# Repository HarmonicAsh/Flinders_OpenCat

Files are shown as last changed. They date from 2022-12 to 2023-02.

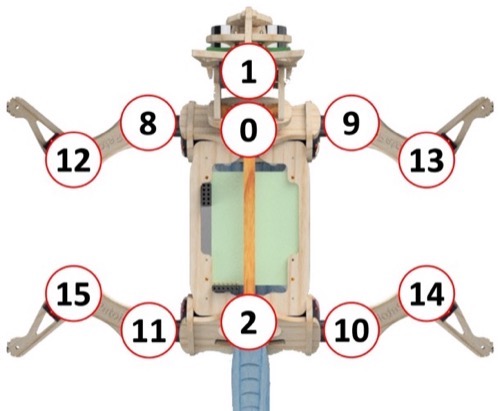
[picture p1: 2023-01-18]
OpenCat1801/pyUI/resources/Nybble.jpeg

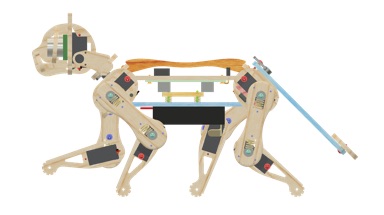
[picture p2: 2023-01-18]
OpenCat1801/pyUI/resources/NybbleWalk.jpeg

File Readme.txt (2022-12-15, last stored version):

**Welcome to the Flinders University OpenCat Project repository!**

Simplfied step by step assembly guide for Nybble:
1. Upload firmwire to the Nyboard using the Petoi Desktop app. Be sure to zero the IMU (gyro sensor) on a flat benchtop or Nybble will not balance well.
https://docs.petoi.com/desktop-app/firmware-uploader

2. To control Nybble with a Rasberry Pi, a pre 4 model must be used due to compatability issues. Follow the Petoi guide to set up the serial port of the Rasberry Pi to interface with the Nybble.
https://docs.petoi.com/api/raspberry-pi-serial-port-as-an-interface

3. Download the OpenCat repository to the Rasberry Pi. With a Github account, the repository can be set up on your Pi using the Pi terminal:
$ sudo apt-get update
$ sudo apt-get install git
$ git config --global user.email "Your@email.com"
$ git config -- global user.name "Your GITHUB username"

To clone the repository to your device, then use:
$ git clone https://github.com/PetoiCamp/OpenCat.git

ALternatively, using the same link, download and install manually.

4. ArdSerial is used to issue serial commands from the Rasberry Pi to the Nyboard. 

https://www.putty.org/
disable ghetty

ardSerial
calibrate
Open cat web interface
ifconfig : find IP address for SSH and VNC to remote control via Wifi

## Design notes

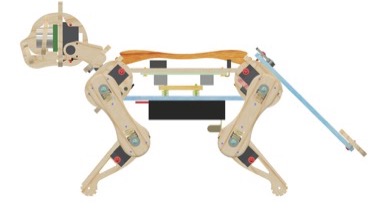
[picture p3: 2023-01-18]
OpenCat1801/pyUI/resources/NybbleStand.jpeg

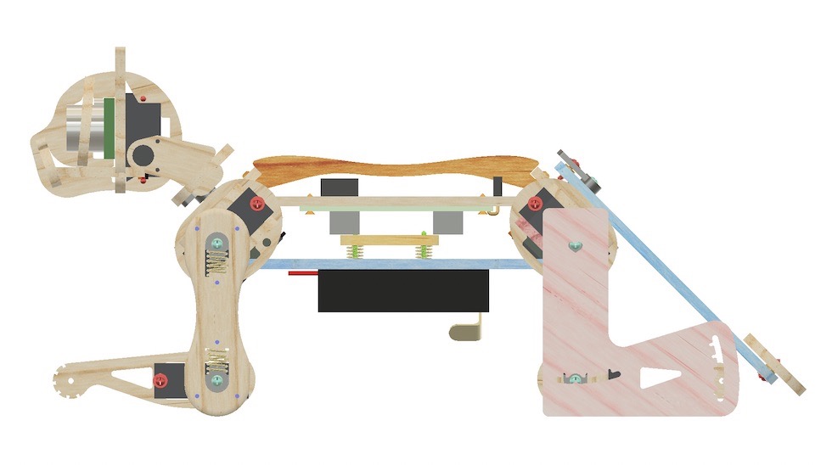
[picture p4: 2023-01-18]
OpenCat1801/pyUI/resources/NybbleRuler.jpeg

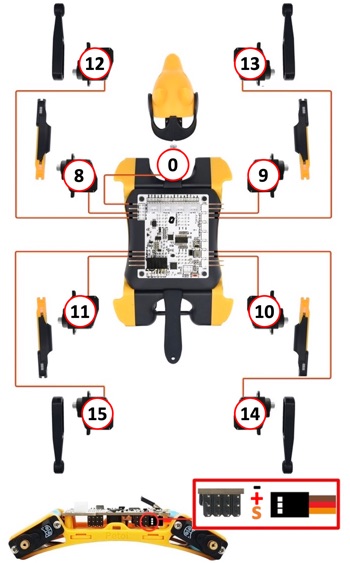
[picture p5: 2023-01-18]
OpenCat1801/pyUI/resources/BittleWire.jpeg

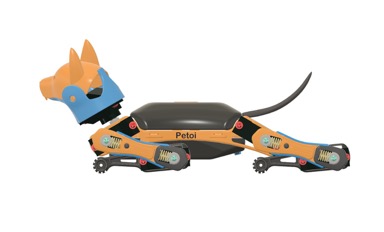
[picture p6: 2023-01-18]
OpenCat1801/pyUI/resources/BittleRest.jpeg

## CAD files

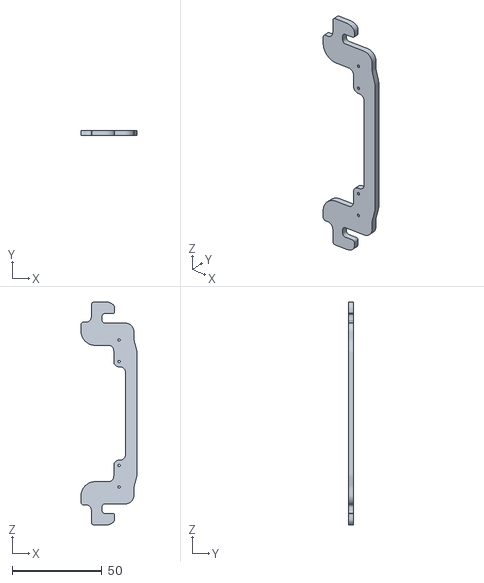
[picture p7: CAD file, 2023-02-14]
CAD components/Nybble_y1.stl
31.3 x 3.00 x 124.4

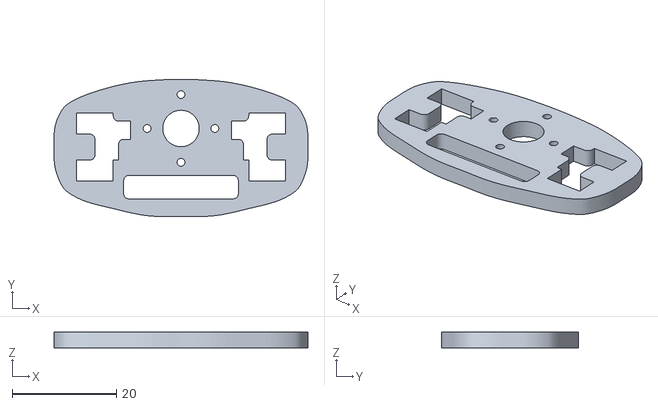
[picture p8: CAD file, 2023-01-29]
CAD components/NybbleDIY/Neck_Base_Plate_MG90S.stl
48.7 x 26.3 x 3.00

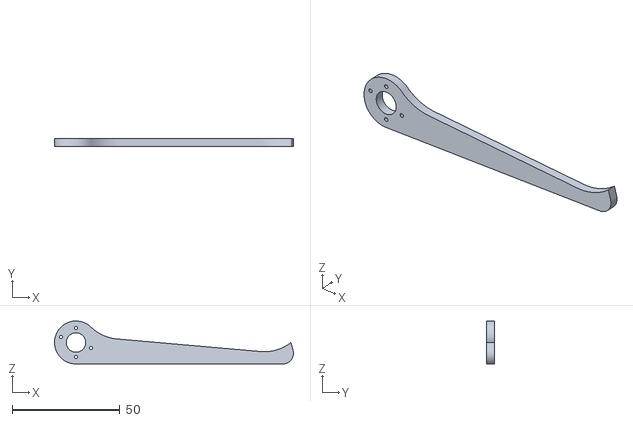
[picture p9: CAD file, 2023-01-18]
OpenCat1801/ModuleTests/testServo/servoTorqueArm.stl
111.2 x 3.50 x 20.0

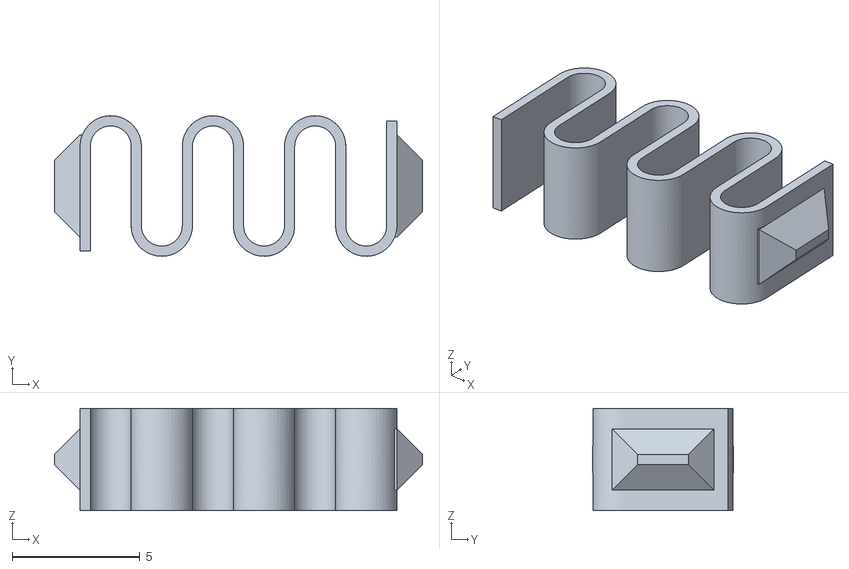
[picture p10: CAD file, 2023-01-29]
CAD components/NybbleDIY/Spring_4.0_.4.stl
14.4 x 5.50 x 4.00

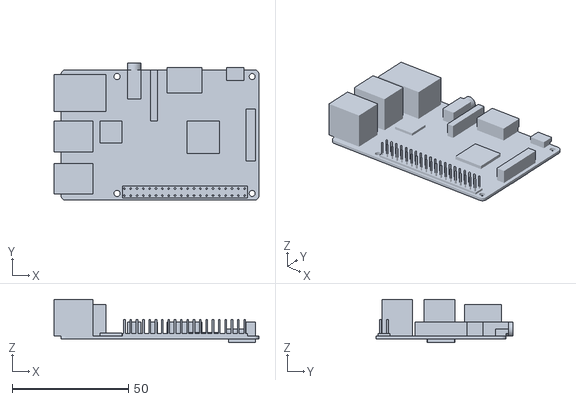
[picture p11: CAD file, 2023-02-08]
CAD components/pi_v6.stl
88.0 x 59.0 x 18.6

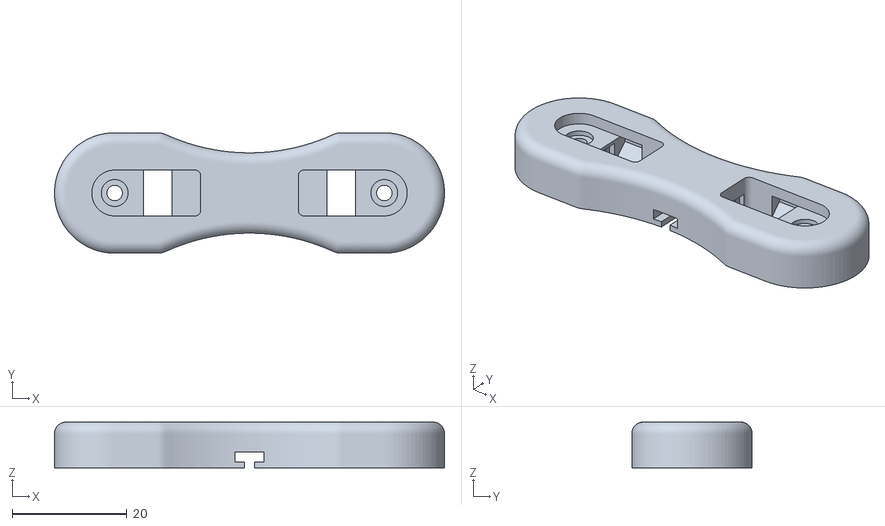
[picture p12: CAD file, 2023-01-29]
CAD components/NybbleDIY/Thigh.stl
68.0 x 21.0 x 8.00

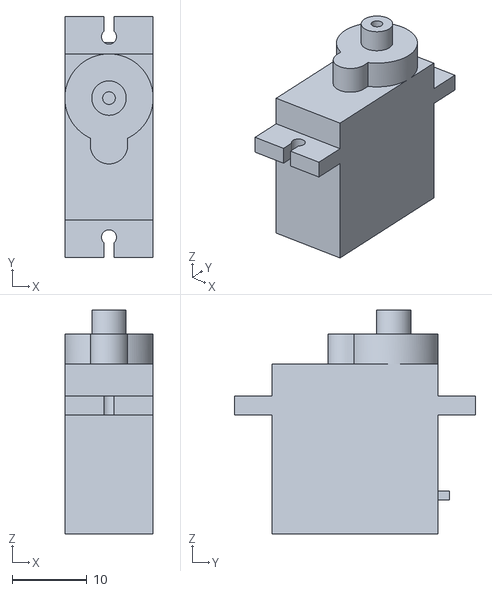
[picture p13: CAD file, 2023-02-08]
CAD components/SG90_v7.stl
11.8 x 32.2 x 29.9

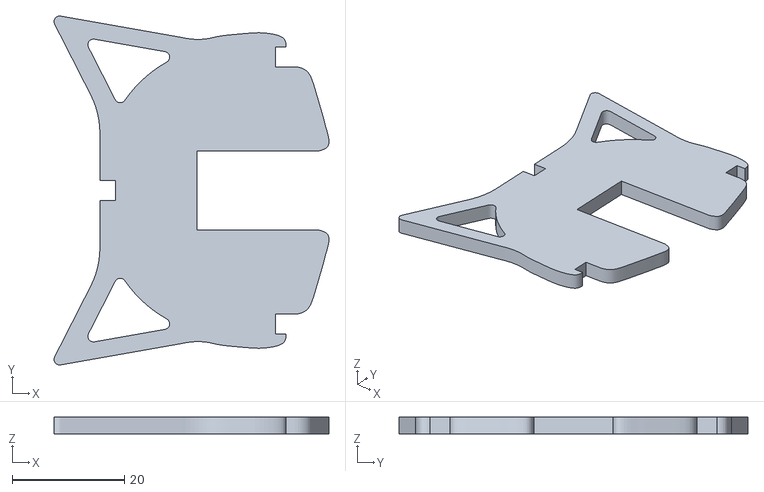
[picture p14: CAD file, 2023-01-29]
CAD components/NybbleDIY/Ears_MG90S.stl
48.9 x 62.1 x 3.00

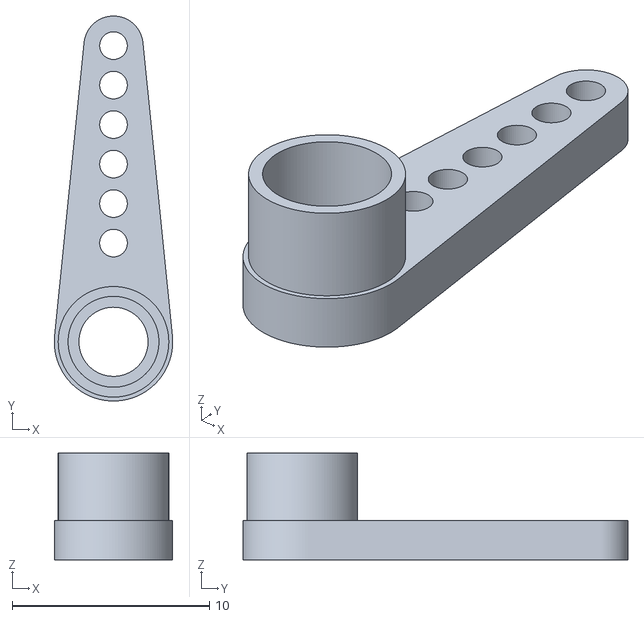
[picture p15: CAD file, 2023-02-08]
CAD components/SG90_arm_v2.stl
6.00 x 19.5 x 5.40

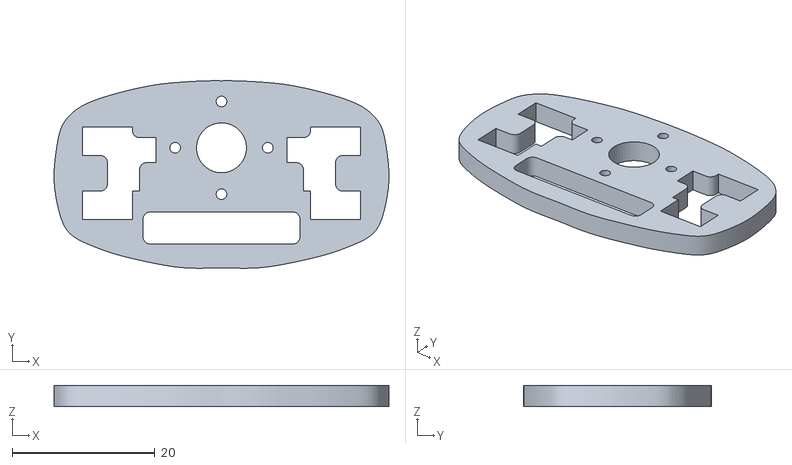
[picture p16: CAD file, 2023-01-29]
CAD components/NybbleDIY/Neck_Base_Plate.stl
47.0 x 26.3 x 3.00

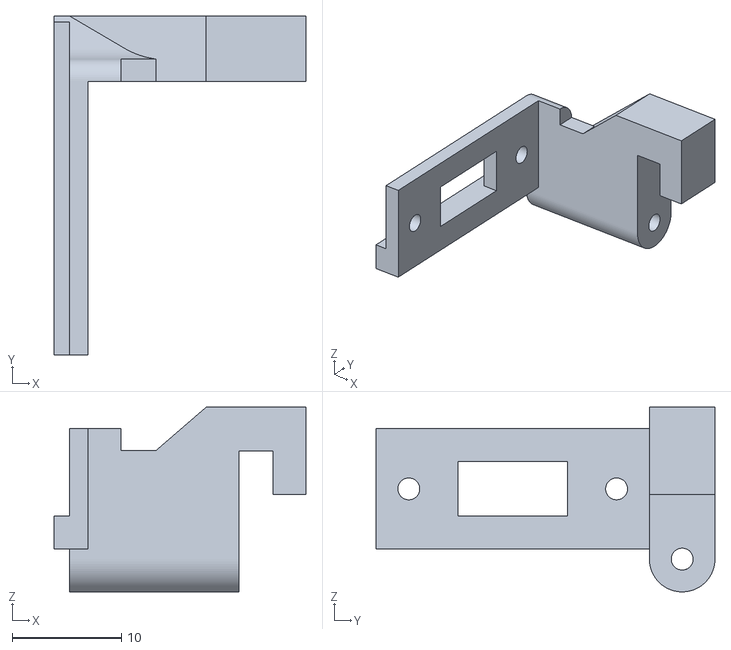
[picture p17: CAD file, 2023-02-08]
CAD components/Pi3B_spacer_R_switch2.stl
23.0 x 31.0 x 16.9

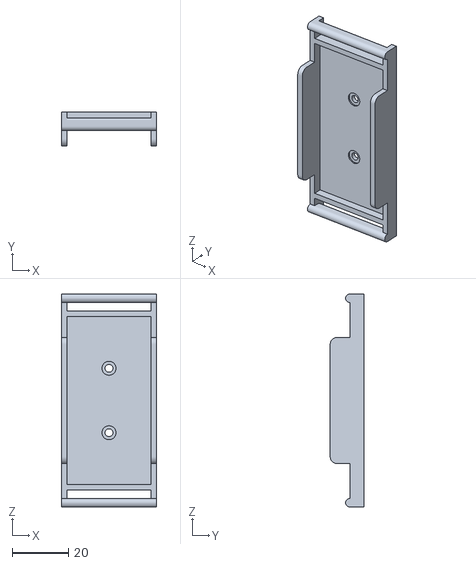
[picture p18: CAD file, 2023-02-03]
CAD components/Battery_holder_2.stl
34.0 x 12.0 x 76.0

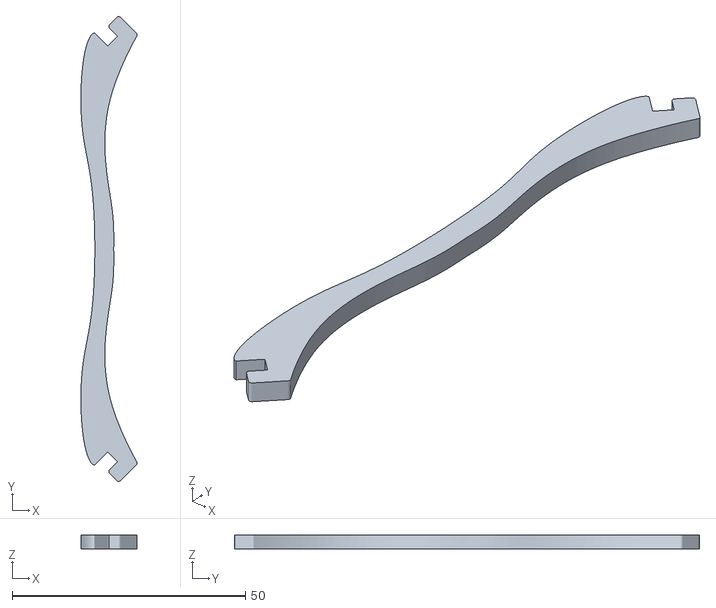
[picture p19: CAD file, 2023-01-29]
CAD components/NybbleDIY/Spine.stl
12.1 x 99.7 x 3.00

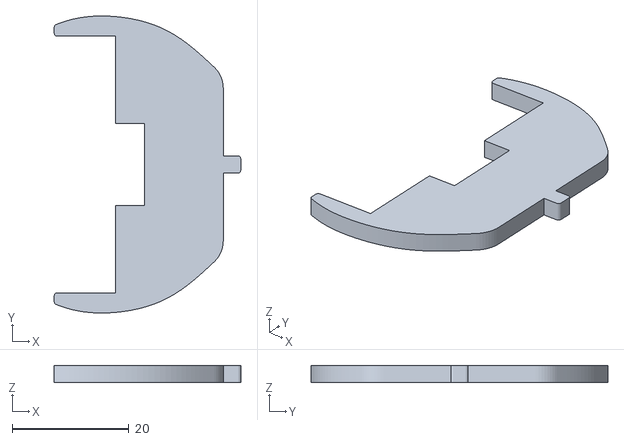
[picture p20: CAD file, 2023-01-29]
CAD components/NybbleDIY/Chin_MG90S.stl
32.0 x 50.9 x 3.00

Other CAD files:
CAD components/Pi3B_spacer_R_switch.stl
CAD components/battery mount rear.stl
CAD components/NybbleDIY/Controller_Mount.stl
CAD components/Battery mount front.stl
CAD components/815 Servo Driver 16 Channel.ipt
CAD components/Base_modded.ipt
CAD components/Base_modded.stl
CAD components/Battery mount front.ipt
CAD components/Battery_holder.iam
CAD components/Battery_holder.ipt
CAD components/Battery_holder_2.ipt
CAD components/Battery_holder_upper.stl
CAD components/Battery_holer_lower.stl
CAD components/Battery_short_holder.ipt
CAD components/Battery_temp.ipt
CAD components/Battery_template.ipt
CAD components/BellyPlate.ipt
CAD components/Braces.ipt
CAD components/Braces.stl
CAD components/Cat_head.iam
CAD components/Chest_Hips.ipt
CAD components/Dowel.ipt
CAD components/Imported Components/Battery_holer_lower/Battery_holer_lower.ipt
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

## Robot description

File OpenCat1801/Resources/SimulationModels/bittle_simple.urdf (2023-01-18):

<?xml version="0.0" ?>
<robot name="bittle_simple">
	<link name="torso">
		<inertial>
			<origin rpy="0.00000 -0.00000 0.00000" xyz="0.00000 0.00000 0.00000"/>
			<mass value="20.00000"/>
			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
		</inertial>
		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
	</link>
	<link name="link1_2">
		<inertial>
			<origin rpy="0.00000 -0.00000 0.00000" xyz="0.00000 0.00000 0.00000"/>
			<mass value="0.00000"/>
			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
		</inertial>
	</link>
	<link name="lfs">
		<inertial>
			<origin rpy="0.00000 -0.00000 0.00000" xyz="0.00000 0.00000 0.00000"/>
			<mass value="0.60000"/>
			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
		</inertial>
		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
	</link>
	<link name="link1_4">
		<inertial>
			<origin rpy="0.00000 -0.00000 0.00000" xyz="0.00000 0.00000 0.00000"/>
			<mass value="0.00000"/>
			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
		</inertial>
	</link>
	<link name="lfk">
		<inertial>
			<origin rpy="0.00000 -0.00000 0.00000" xyz="0.00000 0.00000 0.00000"/>
			<mass value="1.70000"/>
			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
		</inertial>
		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
	</link>
	<link name="link1_6">
		<inertial>
			<origin rpy="0.00000 -0.00000 0.00000" xyz="0.00000 0.00000 0.00000"/>
			<mass value="0.00000"/>
			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
		</inertial>
	</link>
	<link name="rfs">
		<inertial>
			<origin rpy="0.00000 -0.00000 0.00000" xyz="0.00000 0.00000 0.00000"/>
			<mass value="0.60000"/>
			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
		</inertial>
		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
	</link>
	<link name="link1_8">
		<inertial>
			<origin rpy="0.00000 -0.00000 0.00000" xyz="0.00000 0.00000 0.00000"/>
			<mass value="0.00000"/>
			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
		</inertial>
	</link>
	<link name="rfk">
		<inertial>
			<origin rpy="0.00000 -0.00000 0.00000" xyz="0.00000 0.00000 0.00000"/>
			<mass value="1.70000"/>
			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
		</inertial>
		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
	</link>
	<link name="link1_10">
		<inertial>
			<origin rpy="0.00000 -0.00000 0.00000" xyz="0.00000 0.00000 0.00000"/>
			<mass value="0.00000"/>
			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
		</inertial>
	</link>
	<link name="lbs">
		<inertial>
			<origin rpy="0.00000 -0.00000 0.00000" xyz="0.00000 0.00000 0.00000"/>
			<mass value="0.60000"/>
			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
		</inertial>
		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
	</link>
	<link name="link1_12">
		<inertial>
			<origin rpy="0.00000 -0.00000 0.00000" xyz="0.00000 0.00000 0.00000"/>
			<mass value="0.00000"/>
			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
		</inertial>
	</link>
	<link name="lbk">
		<inertial>
			<origin rpy="0.00000 -0.00000 0.00000" xyz="0.00000 0.00000 0.00000"/>
			<mass value="1.70000"/>
			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
		</inertial>
		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
	</link>
	<link name="link1_14">
		<inertial>
			<origin rpy="0.00000 -0.00000 0.00000" xyz="0.00000 0.00000 0.00000"/>
			<mass value="0.00000"/>
			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
		</inertial>
	</link>
	<link name="rbs">
		<inertial>
			<origin rpy="0.00000 -0.00000 0.00000" xyz="0.00000 0.00000 0.00000"/>
			<mass value="0.60000"/>
			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
		</inertial>
		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
	</link>
	<link name="link1_16">
		<inertial>
			<origin rpy="0.00000 -0.00000 0.00000" xyz="0.00000 0.00000 0.00000"/>
			<mass value="0.00000"/>
			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
		</inertial>
	</link>
	<link name="rbk">
		<inertial>
			<origin rpy="0.00000 -0.00000 0.00000" xyz="0.00000 0.00000 0.00000"/>
			<mass value="1.70000"/>
			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
		</inertial>
		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
	</link>
	<joint name="lfsj" type="continuous">
		<parent link="torso"/>
		<child link="link1_2"/>
		<dynamics damping="1.0" friction="0.0001"/>
		<origin rpy="0.00000 -0.00000 0.00000" xyz="-0.04850 0.05050 0.00000"/>
		<axis xyz="1.00000 0.00000 0.00000"/>
	</joint>
	<joint name="jointfix_1_2" type="fixed">
		<parent link="link1_2"/>
		<child link="lfs"/>
		<dynamics damping="1.0" friction="0.0001"/>
		<origin rpy="0.00000 -0.00000 0.00000" xyz="0.00000 0.02300 0.00000"/>
		<axis xyz="0.00000 0.00000 0.00000"/>
	</joint>
	<joint name="lfkj" type="continuous">
		<parent link="lfs"/>
		<child link="link1_4"/>
		<dynamics damping="1.0" friction="0.0001"/>
		<origin rpy="0.00000 -0.00000 0.00000" xyz="0.00750 0.02300 0.00000"/>
		<axis xyz="1.00000 0.00000 0.00000"/>
	</joint>
	<joint name="jointfix_0_4" type="fixed">
		<parent link="link1_4"/>
		<child link="lfk"/>
		<dynamics damping="1.0" friction="0.0001"/>
		<origin rpy="0.00000 -0.00000 0.00000" xyz="0.00000 0.02425 0.00000"/>
		<axis xyz="0.00000 0.00000 0.00000"/>
	</joint>
	<joint name="rfsj" type="continuous">
		<parent link="torso"/>
		<child link="link1_6"/>
		<dynamics damping="1.0" friction="0.0001"/>
		<origin rpy="0.00000 -0.00000 0.00000" xyz="0.04850 0.05050 0.00000"/>
		<axis xyz="1.00000 0.00000 0.00000"/>
	</joint>
	<joint name="jointfix_3_6" type="fixed">
		<parent link="link1_6"/>
		<child link="rfs"/>
		<dynamics damping="1.0" friction="0.0001"/>
		<origin rpy="0.00000 -0.00000 0.00000" xyz="0.00000 0.02300 0.00000"/>
		<axis xyz="0.00000 0.00000 0.00000"/>
	</joint>
	<joint name="rfkj" type="continuous">
		<parent link="rfs"/>
		<child link="link1_8"/>
		<dynamics damping="1.0" friction="0.0001"/>
		<origin rpy="0.00000 -0.00000 0.00000" xyz="-0.00750 0.02300 0.00000"/>
		<axis xyz="1.00000 0.00000 0.00000"/>
	</joint>
	<joint name="jointfix_2_8" type="fixed">
		<parent link="link1_8"/>
		<child link="rfk"/>
		<dynamics damping="1.0" friction="0.0001"/>
		<origin rpy="0.00000 -0.00000 0.00000" xyz="0.00000 0.02425 0.00000"/>
		<axis xyz="0.00000 0.00000 0.00000"/>
	</joint>
	<joint name="lbsj" type="continuous">
		<parent link="torso"/>
		<child link="link1_10"/>
		<dynamics damping="1.0" friction="0.0001"/>
		<origin rpy="0.00000 -0.00000 0.00000" xyz="-0.04850 -0.05050 0.00000"/>
		<axis xyz="1.00000 0.00000 0.00000"/>
	</joint>
	<joint name="jointfix_5_10" type="fixed">
		<parent link="link1_10"/>
		<child link="lbs"/>
		<dynamics damping="1.0" friction="0.0001"/>
		<origin rpy="0.00000 -0.00000 0.00000" xyz="0.00000 -0.02300 0.00000"/>
		<axis xyz="0.00000 0.00000 0.00000"/>
	</joint>
	<joint name="lbkj" type="continuous">
		<parent link="lbs"/>
		<child link="link1_12"/>
		<dynamics damping="1.0" friction="0.0001"/>
		<origin rpy="0.00000 -0.00000 0.00000" xyz="0.00750 -0.02300 0.00000"/>
		<axis xyz="1.00000 0.00000 0.00000"/>
	</joint>
	<joint name="jointfix_4_12" type="fixed">
		<parent link="link1_12"/>
		<child link="lbk"/>
		<dynamics damping="1.0" friction="0.0001"/>
		<origin rpy="0.00000 -0.00000 0.00000" xyz="0.00000 -0.02425 0.00000"/>
		<axis xyz="0.00000 0.00000 0.00000"/>
	</joint>
	<joint name="rbsj" type="continuous">
		<parent link="torso"/>
		<child link="link1_14"/>
		<dynamics damping="1.0" friction="0.0001"/>
		<origin rpy="0.00000 -0.00000 0.00000" xyz="0.04850 -0.05050 0.00000"/>
		<axis xyz="1.00000 0.00000 0.00000"/>
	</joint>
	<joint name="jointfix_7_14" type="fixed">
		<parent link="link1_14"/>
		<child link="rbs"/>
		<dynamics damping="1.0" friction="0.0001"/>
		<origin rpy="0.00000 -0.00000 0.00000" xyz="0.00000 -0.02300 0.00000"/>
		<axis xyz="0.00000 0.00000 0.00000"/>
	</joint>
	<joint name="rbkj" type="continuous">
		<parent link="rbs"/>
		<child link="link1_16"/>
		<dynamics damping="1.0" friction="0.0001"/>
		<origin rpy="0.00000 -0.00000 0.00000" xyz="-0.00750 -0.02300 0.00000"/>
		<axis xyz="1.00000 0.00000 0.00000"/>
	</joint>
	<joint name="jointfix_6_16" type="fixed">
		<parent link="link1_16"/>
		<child link="rbk"/>
		<dynamics damping="1.0" friction="0.0001"/>
		<origin rpy="0.00000 -0.00000 0.00000" xyz="0.00000 -0.02425 0.00000"/>
		<axis xyz="0.00000 0.00000 0.00000"/>
	</joint>
</robot>

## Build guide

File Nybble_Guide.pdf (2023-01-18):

## Nybble: Basic Assembly and Serial Connections

S.Thiele, Flinders University
08/01/2023, revision 1
- A simplified instruction set, developed directly from Petoi instructions, designed to be a simple step-by-step set of instructions to build your own Nybble cat! This guide is aimed at those who find that they struggle with direction in establishing the fundamentals of playing with Nybble. All Nybble related information in this guide is available in more detail from Petoi. I also highly recommend the Petoi Forum (https://www.petoi.camp/) for ideas, inspiration and additional assistance. It is full of great content and a good way to learn how to make your Nybble stand out from the crowd!

## 1 Assembly and Setting up the Raspberry Pi Interface

1. Upload firmwire to the Nyboard using the Petoi Desktop app. Be sure to zero the IMU (gyro sensor) on a flat bench-top or Nybble will not balance well. See Petoi firmware uploader (https://docs.petoi.com/desktop-app/firmware-uploader) for additional information.
2. Carry out the assembly process, following the process outlined by Petoi: Petoi Nybble Instructions. (https://nybble.petoi.com/chapter1) Joint calibration can be carried out via USB as per the instructions guide or with the serial input after step 6.
3. To use a Raspberry Pi for controlling Nybble, download the OpenCat repository to the Raspberry Pi. With a Github account, the repository can be set up on your Pi using the Pi terminal:
sudo apt-get update
sudo apt-get install git
Optionally, to link your own GitHub account:
git config –global user.email ”Your@email.com”
git config – global user.name ”Your GITHUB username”
4. To clone the OpenCat repository to your device, then use:
git clone https://github.com/PetoiCamp/OpenCat.git

Alternatively, using the same link, download and install manually. All Git repositories can be downloaded by simply replacing the URL with the URL of the desired repository.
5. Follow the Petoi guide (https://docs.petoi.com/api/raspberry-pi-serial-port-as-an-interface) to set up the serial port of the Raspberry Pi to interface with the Nybble.
6. ArdSerial.py is used to issue serial commands from the Raspberry Pi to the Nyboard. Serial commands can be found here: Petoi Serial Protocol. (https://docs.petoi.com/serial-protocol#arduino-ide-as-an-interface)

## 2 Issuing commands to the Raspberry Pi via Wi-Fi and a remote terminal

1. Connect the Raspberry Pi to the same WiFi network as the control device.
2. Using ifconfig in the Raspberry Pi terminal, find IP address of the Raspberry Pi.
ifconfig
3. Download the latest PuTTY client (https://www.putty.org/) to the control device. A remote connection to the Raspberry Pi can be established by following simple guide. (https://raspberrypi4dummies.wordpress.com/2013/03/17/connect-to-the-raspberry-pi-via-ssh-putty/)

4. After establishing the connection, use the PuTTY terminal as per steps 1.5 and 1.6 to issue commands to Nybble!

## 3 Using the OpenCatWeb Interface

1. Download or clone the OpenCatWeb repository (https://github.com/leukipp/OpenCatWeb.git) to your device
2. Follow the setup instructions in the read-me either from the cloned repository or here. (https://github.com/leukipp/OpenCatWeb) Stop when you reach the section called ”First Start”, changes must be made to enable the connection to be made.
3. Enable SSH in the Raspberry Pi terminal and configuration settings and acquire the IP address of the Raspberry Pi on the network using ifconfig.
sudo raspi-config

ifconfig

4. html.escape supersedes cgi.escape from Python 3.2 onwards (issues arise in OpenCatWeb scripts as a result of this) and additional compatability issues may occur. A workaround is to install Python 2.7 and alter app.py to run on the older version. Begin by installing Python 2.7, using the Raspberry Py terminal.
sudo apt-get update

sudo apt-get install python2.7

reboot

5. Open app.py from the OpenCatWeb directy with a text or Python editor. Alterations are made to use the known IP address and to reconfigure the script to use Python 2.7. Observe the following sections of code:
!/usr/bin/python | at line 1
HOST = ’0.0.0.0’ | at line 8
The first line must be altered to run Python 2.7, and new lines added directly beneath to reconfigure the default location of packages, as these will not be installed in the standard Python 2.7 location. Replace line 1 with the following 3 lines:
!/usr/bin/python2.7
import sys
sys.path.append(‘/usr/lib/python3/dist-packages‘)
Now simply input the IP address of your Raspberry Pi into the HOST line and save the code. For example: HOST = ’192.168.0.32’
6. Next, bus.py must be altered to suit the correct serial configuration. Code lines 9 to 18 are responsible for setting up the serial connection. Note in particular, the following 2 lines:
port = ’/dev/ttyAMA0’,
baudrate = 57600,
To allow OpenCatWeb to function, these must be re-defined to suit the ttyS0 serial port. Changing the lines as follows:
port = ’/dev/ttyS0’,
baudrate = 115200,

7. Ensure that Flask and serial are installed: pip install Flask
pip install serial
8. You should now be able to resume following the read-me (https://github.com/leukipp/OpenCatWeb) for OpenCatWeb from the ”First Start” section.

## 4 Arduino Serial Output

1. The Arduino serial monitor can be used with both Bluetooth or a USB cable as an interface. Connect the desired adaptor to the Nyboard and either connect the USB cable to your control device or confirm that Nyble is visible over Bluetooth.
2. Open the Arduino IDE, choose an Arduino UNO as the board and choose the correct COM port. If using a USB cable, you should be able to view which COM port is connected to Nybble, and alternatively determine the COM port of your Bluetooth connection. Open the serial monitor and ensure that the settings of the serial monitor is set to ”No line ending” and ”115200 baud”.
3. If a succesful connection is made, Nybble will begin by relaying some data back to the serial monitor. If you can clearly see information from the Nybble, you are ready to go! Issue commands to Nybble observed in the Serial Protocol (https://docs.petoi.com/serial-protocol) documentation to control her!

## 5 Raspberry Pi with Ubuntu Via PuTTY

1. Install Ubuntu via the Raspberry Pi imager. (https://www.raspberrypi.com/software/) The server version can be used for simplicity, performs much better on older Raspberry Pi hardware. It is necessary to open the advanced options section on the main page, and enable SSH and enter desired log-in details of the Raspberry Pi, to allow access over a network connection. For additional information, follow the Ubuntu Installation Guide. (https://ubuntu.com/tutorials/how-to-install-ubuntu-on-your-raspberry-pi#1-overview)
2. Download the latest PuTTY client (https://www.putty.org/) to the control device. A remote connection to the Raspberry Pi can be established by following simple guide.You (https://raspberrypi4dummies.wordpress.com/2013/03/17/connect-to-the-raspberry-pi-via-ssh-putty/) can use the host name given during the installation setup to connect to the Raspberry Pi, or the IP address.
3. Ubuntu lacks some essential Python packages required to use ardSerial.py. It is useful to install the Python pip package as well as tkinster.
sudo apt-get update
sudo apt install python3-pip
sudo apt install python3.8-tk
sudo dmesg | grep tty [check that ttyS0 is enabled or see what it is about⁉]
Can install a desktop UI if needed: sudo apt install xubuntu-desktop sudo apt install lubuntu-desktop

## 6 Kinematic Model- Skill Creation

Kinematic Model (https://github.com/ger01d/kinematic-model-opencat) pip3 install –upgrade numpy sudo apt-get install libatlas-base-dev

## 7 Flinders University Customisations

This section introduces adaptations made during the assembly and testing of the Nybble project.

1. Customised Battery Holder:
A replacement battery holder was developed to suit a 7.4 850mAh LiPo battery (https://www.auselectronicsdirect.com.au/7.4v-850mah-lipo-2s-battery-pack-with-jst-connecto) featuring a JST connector, using an inline switch. (https://www.jaycar.com.au/inline-jst-switch-kit/p/SS0826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) The mounting was designed to retain Nybble’s sliding battery mechanism, to allow for adjustments to her centre of gravity. The current itteration of the design is entirely 3D printed, and is ready to use after installation to the lower frame of Nybble. Due to tolerancing from the print, drilling of the base may be required to fit the original locating collars, however heating the collars with a soldering iron is also effective.
2. Petoi/Raspberry Pi Camera Holder:
As Nybble does not have the facilities to equip a camera, as Bittle would, a clip on camera mount was designed. It sits over the head of Nybble, and clips around the ultrasonic sensor. The camera design has 2 versions, one to suit the Petoi camera (https://www.petoi.com/products/intelligent-camera-module) and one to suit a Raspberry Pi camera, (https://www.raspberrypi.com/products/camera-module-v2/) to better facilitate projects requiring additional functionality. Details about setting up the camera can be found here. (https://docs.petoi.com/extensible-modules/mu-camera)
3. Raspberry Pi 3B spaced mounts:
As Nybble was designed around a Raspberry Pi 3A, with a smaller footprint than later models, the design of the body inhibits the use of full scale Pi models, with issues accessing most of the USB ports. Spacers have been designed, that use the Nyboard mounting screws to secure them to the body, and allows self-tapping screws to be fitted to support the Raspberry Pi. Additional requirements are a 2x5 pin spacer and some self-tapping screws.

## 8 Acknowledgments

Here will be acknowledgements to the Cat man himself, leukipp and other sources

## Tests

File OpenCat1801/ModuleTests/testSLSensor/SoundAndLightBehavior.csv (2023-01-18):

LIGHT | READING | THRESHOLD
brighter | lower
darker | higher | 850
LIGHT |  | SOUND
_LEVEL | _CHANGE | _LEVEL | _BEHAVIOR
dark |  | low | rest
 |  | high | sit
high |  | low | sit
 |  | high | stand
 | fast light
 | fast dim
bright |  |  | proportional

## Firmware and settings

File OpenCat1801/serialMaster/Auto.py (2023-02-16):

#!/usr/bin/python3
# -*- coding: UTF-8 -*-

#Req pyserial and pip3
#sudo apt-get install python3-tk
#Use to install Pip3 as req: sudo apt-get -y install python3-pip
#https://wavlist.com/animals-cats-20-wavs/ cat sounds found here <-


import random
import sys
import time
import math
from pygame import mixer
sys.path.append("..")
from ardSerial import *
from SR04 import *
        
         
def load_sound():
        mixer.init()  #Initialise pigame mixer for audio
        print("Loading sounds...")
        global cat1
        global cat2
        global cat3
        global cat4
        global cat5
        cat1 = mixer.Sound("cat1.wav")   #load wav files
        cat2 = mixer.Sound("cat2.wav")   #load wav files
        cat3 = mixer.Sound("cat3.wav")   #load wav files
        cat4 = mixer.Sound("cat4.wav")   #load wav files
        cat5 = mixer.Sound("cat5.wav")   #load wav files
        print("Loading sounds completed.\n") #Load_sound (Loads sounds for the cat to "play")

def direction():
        print("\n---------------------changing direction---------------------------")
        send(goodPorts,['ksit',0.5],)  #Sit, then look straight ahead and measure the distance to the obstruction
        send(goodPorts,['i', [0, 0, 1, -30], 0.5],)
        time.sleep(0.25)
        dist = distance()
        print("Distance (non-averaged) = ", dist)
        if dist >= 60:
            print("The obstruction appears to have moved...")
            random_behaviour()
            motion()
        else:
            print("The obstruction is... ")
            print(dist, " cm in front")
            send(goodPorts,['i', [0, 50, 1, -38], 0.5],) #Look left and measure the distance to the obstruction
            global dist_left 
            dist_left = distance()
            print(dist_left, " cm to the left")
            send(goodPorts,['i', [0, -50, 1, -38], 0.5],) #Look right and measure the distance to the obstruction
            global dist_right
            dist_right = distance()
            print(dist_right, " cm to the right")
            send(goodPorts,['i', [0, 0, 1, -30], 0.5],)
            dist = distance()
            print("Distance (non-averaged) = ", dist)

        if dist >= 60:
            motion()
        elif dist_left < dist_right:
            print("Going right..")
            time_mod = 0.5+1*dist_left/dist_right
            print("Time delay = ", time_mod)
            cat_meow(random.randint(0,2))
            right_until(time_mod)
            
        elif dist_left > dist_right:
            print("Going left..")
            time_mod = 0.5+1*dist_right/dist_left
            print("Time delay = ", time_mod)
            cat_meow(random.randint(0,2))
            left_until(time_mod)
        else:
            print("These measurements don't make sense... check ultrasonic sensor")
            send(goodPorts,['kbalance',2],)
            send(goodPorts,['krest',1],)
            Nybble_sleep()      

        print("------------------------------------------------------------------\n")
        motion() #Direction (Code for the cat to measure distances to decide which direction to turn in)

def random_behaviour():
        behaviour = random.randint(0,7)
                
        cat_meow(random.randint(0,4))
        if behaviour == 0:
            send(goodPorts,['kstr',0],)
        elif behaviour == 1:
            send(goodPorts,['kbuttUp',0],)
        elif behaviour == 2:
            send(goodPorts,['kstr',0],)
            send(goodPorts,['kbuttUp',1],)
        elif behaviour == 3:
            send(goodPorts,['kck',0],)
        elif behaviour == 4:
            send(goodPorts,['kck',0],)
            send(goodPorts,['kbk',1],)
            cat_meow(random.randint(0,2))
            send(goodPorts,['kstr',0],)
        elif behaviour == 5:
            pass
        elif behaviour == 6:
            send(goodPorts,['kvt',3],) #Random_behaviour (Code for the cat to randomly "behave" differently, when presented with an obstruction)

def cat_meow(int):
        if int == 0:
            mixer.Sound.play(cat1)
        elif int == 1:
            mixer.Sound.play(cat2)
        elif int == 2:
            mixer.Sound.play(cat3)
        elif int == 3:
            mixer.Sound.play(cat4)
        elif int == 4: #File 4 currently has problems, using 3 again instead    
            mixer.Sound.play(cat3) #Cat_meow (Use to make the cat meow)   
            
def right_until(int):        
        dist = distance()
        send(goodPorts,['kbkL',int],)
        while dist <=60:
            time.sleep(0.2)
            dist = dist_av()
        motion() #Right_until (The cat will turn right until the obstruction is nolonger detected)

def left_until(int):
        dist = distance()
        send(goodPorts,['kbkR',int],)
        while dist <= 60:
            time.sleep(0.2)
            dist = dist_av()
        motion() #Left_until (The cat will turn left until the obstruction is nolonger detected)

def Nybble_sleep(): #Shuts down Nybble when the script has finished
        print("\nTerminating... farewell!")
        send(goodPorts,['krest',1],)  #Rest
        closeAllSerial(goodPorts)
        logger.info("finish!")
        os._exit(0) #Nybble_sleep (Puts the cat into a shutdown state)

def motion():
        global speed
        global speed_mod

        if speed == "1":
            print("attempting speed 1")
            speed_mod = 2
            send(goodPorts,['kcrF',1],)           
        elif speed == "2":
            print("attempting speed 2")
            speed_mod = 2
            send(goodPorts,['kwkF',1],)
        elif speed == "3":
            print("attempting speed 3")
            speed_mod = 0.5
            send(goodPorts,['ktrF',1],)

        dist = dist_av()

        while dist >= 20:
            dist = dist_av()
            time.sleep(0.01)            
        else:
            direction() #Motion (Starts the cat moving forwards, based on speed setting)


def start_cat():
        send(goodPorts,['d',0],) # rest position and shuts off all servos
        print("\n \n------------------------------------------------------------------")
        print("Welcome to the Flinders OpenCat project. Enter a command to begin!") 
        print("------------------------------------------------------------------")
        print("'go'' to commence automated motion") 
        print("'dist' prints ulstrasonic sensor measured distance for 10 seconds") 
        print("'serial' to use Petoi commands directly as a serial input") 
        print("'sound' to test sound output") 
        print("'quit' to terminate...") 
        print("'test' to operate the function test() as required") #Start cat function (lists main menu options)


def audio_test():
        for i in range(4):
            print("Testing meow number ", i)
            cat_meow(i)
            time.sleep(2) #Test_audio (Tests the playback of audio)

def dist_init():
        global dist_arr
        global arr_pos
        dist_arr = [0, 0, 0, 0, 0]
        send(goodPorts,['kbalance',1],)  #Stand up and wait for 1 second
        for x in range(5):
            dist_arr[x] = distance()
            time.sleep(0.1)
        print("[ ",dist_arr[0]," ",dist_arr[1]," ",dist_arr[2]," ",dist_arr[3]," ",dist_arr[4], " ] ")
        time.sleep(1)
        print("Array full..")
        arr_pos = 0
        total = 0
        #return dist_add(arr_pos, dist_arr)    #to call:   dist, arr_pos, dist_arr = dist_init(arr_pos,dist_arr)
        #return arr_pos, dist_arr  # to call: arr_pos, 
        
def dist_av():
        global dist_arr
        global arr_pos
        total = 0
        dist_arr[arr_pos] = distance()
        for i in range(5):
            total += dist_arr[i]
        dist = total/5
        print("Distance = ", dist, "cm")
        time.sleep(0.0025)
        arr_pos += 1
        if arr_pos == 5:
            arr_pos = 0
        else:
            pass
        return dist
       # return dist, arr,pos, dist_arr   # to call:     dist, arr_pos, dist_arr = dist_add(arr_pos,dist_arr)
        

def test():
        dist_init()
        while True:
            dist_av()
            time.sleep(1) #Test (Add code here for simpler testing)   
        
def gyro_toggle(int):
        print("Running gyroscope toggle")
        if int == 3: #Initial setup
            global gyro_status 
            send(goodPorts,['g',0],)# toggle gyroscope (increases cat speed)
            gyro_status = 1
            print("Gyroscope activated (enabled)")

        if int == 0:
            if gyro_status == 0:
                print("Gyroscope already inactive")
                
            else:
                send(goodPorts,['g',0],)# toggle gyroscope (increases cat speed)
                gyro_status = 0
                print("Gyroscope deactive (disabled)")
        elif int == 1:
            if gyro_status == 0:
                send(goodPorts,['g',0],)# toggle gyroscope (increases cat speed)
                gyro_status = 1
                print("Gyroscope activated (enabled)")
            else:
                print("Gyroscope already active")
        elif int == 2:
            if gyro_status == 0:
                send(goodPorts,['g',0],)# toggle gyroscope (increases cat speed)
                gyro_status = 1
                print("Gyroscope enabled (toggled)")
            else:
                send(goodPorts,['g',0],)# toggle gyroscope (increases cat speed)
                gyro_status = 0
                print("Gyroscope deactivated (toggled)") #Gyro_toggle (toggles gyroscope)
            
def read_inputs():
        command = input() #Reads serial inputs

        if command == "go":
                global speed
                print("\nGo command recognised... let's go!")
                send(goodPorts,['kbalance',1],)  #Stand up and wait for 1 second
                gyro_toggle(1) #Enable gyroscope
                cat_meow(3)                
                print("Set speed from 1-3")
                speed = input()
                print("Speed ", speed, " selected")
                dist_init()
                dist_av()
                motion()  #Start walking forwards and attempt to avoid walls

        elif command == "dist": #prints the distance signal of the ultrasonic sensor
                send(goodPorts,['ksit',0.5],)  #Sit, then look straight ahead and measure the distance to the obstruction
                send(goodPorts,['i', [0, 0, 1, -30], 0.5],)
                print("\nMeasured distance (centimetres)")
                for i in range(20):
                    print(distance()) 
                    time.sleep(1)
                start_cat()

        elif command == "test": #Runs test() once
                print("\nRunning test()")
                test()
                start_cat()

        elif command == "sound": #Runs test() once
                print("\nRunning audio test()")
                audio_test()
                start_cat()
  
        elif command == "serial": #allows the input of Petoi serial commands
                serial_comm = 1
                while serial_comm == 1:
                    print("\nWaiting for a Petoi serial command... back to return, quit to exit")
                    command = input()
                    if command == "quit": #Terminate the code
                        Nybble_sleep() 
                    elif command == "back": #Return to main command meny
                        start_cat()
                        serial_comm = 0
                    else: 
                        send(goodPorts,[command,0],) #Sends an input directly to Nybble. Use Petoi documentation for commands
                        time.sleep(0.2)

        elif command == "quit":#Terminate the code
                Nybble_sleep()  #Read inputs and directs to appropriate functions
        
if __name__ == '__main__':
    try:
        '''
        testSchedule is used to test various serial port commands
        '''
        load_sound()
        goodPorts = {}
        connectPort(goodPorts)
        t=threading.Thread(target = keepCheckingPort, args = (goodPorts,))
        t.start()
        parallel = False
        time.sleep(1)
        gyro_toggle(3) # switch gyroscope on (begins off), runs startup code
        send(goodPorts,['d',1],) # rest position and shuts off all servos
        send(goodPorts,['z',1],) # disable random behaviour
        start_cat()
        
        while True:
            read_inputs()
    
    except Exception as e:
        logger.info("Exception")
        closeAllSerial(goodPorts)
        os._exit(0)
        raise e

    finally:
        send(goodPorts,['krest',0.5],)
        closeAllSerial(goodPorts)
        os._exit(0) #Main code body

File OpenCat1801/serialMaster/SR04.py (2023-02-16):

# Test code for the RUS04 built in ultrasonic sensor

#Copied code from SR04.py and modified
#Libraries (please install Python GPIO library first!!)
from math import dist
import RPi.GPIO as GPIO
import time
 
GPIO.setmode(GPIO.BCM) #GPIO Mode (BOARD / BCM)
SIG = 18 #set GPIO Pin

def distance():
    GPIO.setup(SIG, GPIO.OUT)
    GPIO.output(SIG, True)
    time.sleep(0.02)
    #time.sleep(0.00001)
    GPIO.output(SIG, False)

    StartTime = time.time()
    StopTime = time.time()
    # save StartTime

    GPIO.setup(SIG, GPIO.IN)
    while GPIO.input(SIG) == 0:
        StartTime = time.time()
    # save time of arrival
    while GPIO.input(SIG) == 1:
        StopTime = time.time()
    # time difference between start and arrival
    TimeElapsed = StopTime - StartTime
    # multiply with the sonic speed (34300 cm/s)
    # and divide by 2, because there and back
    distance = (TimeElapsed * 34300) / 2

    return distance


if __name__ == '__main__':
    try:
        while True:
            dist = distance()
            print ("Measured Distance = %.1f cm" % dist)
            time.sleep(1)
 
        # Reset by pressing CTRL + C
    except KeyboardInterrupt:
        print("Measurement stopped by User")
        GPIO.cleanup()

        
   

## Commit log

2023-01-18 Added files
    Added initial version of guide.
    Added OpenCat files for faster editing and transfers
    [SoundAndLightBehavior.csv, bittle_simple.urdf, servoTorqueArm.stl]
2023-01-18 Update test_auto.py
    Corrected missing comma
    [test_auto.py]
2023-01-18 Update test_auto.py
    Rectified syntax errors
    [test_auto.py]
2023-01-18 Update test_auto.py
    Increased timers of walking processes
2023-01-18 Update test_auto.py
    Altered timings and added code to disable the gyroscope
2023-01-19 Updated new test codes
    Initial upload of ultrasonic sensor code
2023-01-19 test_auto.py
    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
    [test_auto.py]
2023-01-19 test_auto.py
    Fault finding; changed suspect syntax issue
    [test_auto.py]
2023-01-23 CAD files
    Added Inventor files to repository
    [Braces.ipt, Chest_Hips.ipt, PiMount_spaced_fr.ipt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]
2023-01-24 test_auto
    Multiple changes (uncategorised)
    [Dowel.ipt, Pi_lid.0034.ipt, Pi_lid.ipt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]
2023-01-24 test_auto.py
    Update distance measurement function
    [Braces.0010.ipt, Braces.ipt, Braces.stl]
2023-01-27 Various
    Added 3D files
    Updated SR04 code to suite Petoi sensor
    [Pi3B_spacer_F.ipt, Pi3B_spacer_F.stl, Pi3B_spacer_R.0001.ipt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]
2023-01-28 Updates
    Updated 3D models
    Updated SR04 to suit single wire comms
    [Pi3B_spacer_R.0001.ipt, Pi3B_spacer_R.0002.ipt, Pi3B_spacer_R.ipt]
2023-01-29 Battery_holder.
    Added battery holder CAD file and battery file
    [Battery_holder.0007.ipt, Battery_holder.ipt, Battery_template.ipt]
2023-01-29 NybbleDIY
    Added Nybble DIY for easy access
    [BellyPlate.stl, BellyPlate_MG90S.stl, Chest_Hips.stl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]
2023-01-30 battery holder 3D files
    Re-designed battery holder to alter installation method
    [Battery_holder.0007.ipt, Battery_holder.0010.ipt, Battery_holder.ipt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]
2023-01-30 3D files-various
    Updated battery holder
    [Base_modded.ipt, Battery_holder.0002.iam, Battery_holder.iam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]
2023-01-30 3D updates
    Updated base component
    [Base_modded.0001.ipt, Base_modded.ipt]
2023-01-30 3D file update
    [815 Servo Driver 16 Channel.ipt, Base_modded.0001.ipt, Base_modded.0004.ipt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]
2023-01-31 Various
    Updated 3D files and assembly
    Redesigned battery holder and lower chassis
    Updated timings and instructions in test_auto
    [Base_modded.0004.ipt, Base_modded.0007.ipt, Base_modded.ipt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]
2023-02-03 Multiple changes
    Added audio files
    Added basic code for audio playback
    Updated battery holder and switch mounts (CAD)
    [Battery_holder_2.0001.ipt, Battery_holder_2.ipt, Battery_holder_2.stl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]
2023-02-08 Code restructure
    [Pi3B_spacer_R_switch2.0004.ipt, Pi3B_spacer_R_switch2.ipt, Pi3B_spacer_R_switch2.stl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]
2023-02-08 test_auto,py
    Reverted some changes and tidied code
    [test_auto.py]
2023-02-08 test_auto.py
    Rectified syntax error with else statement
    [test_auto.py]
2023-02-09 test_auto.py
    Fixed serial output problem
    [test_auto.py]
2023-02-09 test_auto.py
    Rectiifed missing lines in turn_right()
    [test_auto.py]
2023-02-09 test_auto.py
    Added missing variables
    [test_auto.py]
2023-02-09 test_auto.py
    Added serial prints to direction changes
2023-02-09 test_auto.py
    Added gyroscope toggle to random behaviour
2023-02-13 test_auto.py
    Named all functions and added an audio test function
    [Cat_head.0001.iam, Cat_head.iam, Chin.ipt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]
2023-02-13 test_auto.py
    Rectified code errors in audio test function
    [test_auto.py]
2023-02-14 test_auto.py
    Rectified issue with time modifiers for object avoidance code
    [BellyPlate.ipt, New_body.0001.iam, New_body.iam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]
2023-02-14 Update test_auto.py
    Edited broken cat5 sound file to use a different sound until rectified
    [test_auto.py]
2023-02-14 Update test_auto.py
    Added code to enable and disable the gyroscope
2023-02-14 Update test_auto.py
    Rectified faults in gyroscope code
2023-02-14 Update test_auto.py
    Test code in motion function for gyroscope control
2023-02-15 test_auto.py
    New test code for ultrasonic sensor readings
    [BellyPlate.0001.ipt, BellyPlate.ipt, Chest_Hips.ipt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]
2023-02-15 test_auto.py
    Hope and pray
    [BellyPlate.0001.ipt, BellyPlate.ipt, Chest_Hips.ipt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]
2023-02-15 test_auto.py
    Moved new sensor code to test section
2023-02-15 test_auto.py
    Ammended array issues
    [test_auto.py]
2023-02-16 SR04.py
    Changed pulse timer to match Arduino code
2023-02-16 SR04
    Added averaging loop to observe sensor changes
